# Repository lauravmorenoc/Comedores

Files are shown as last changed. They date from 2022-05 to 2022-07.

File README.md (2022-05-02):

# Comedores
Uno de los servicios que se busca mejorar por medio del proyecto "Campus Inteligente", corresponde al servicio de comedores de la Universidad Nacional de Colombia, sede Bogotá.

## Funcionamiento actual del sistema en la Universidad
Actualmente, los usuarios se dirigen a cualquiera de los comedores de la universidad, sin conocimiento previo de qué tan lleno se encuentra. Al llegar, hacen una fila física hasta el lugar en el que se sirven los almuerzos. Una vez aquí, toman una bandeja, y los empleados van presentando las opciones disponibles (por ejemplo, para escoger entre carne de res o pollo), de las cuales los usuarios eligen su opción favorita. En base a esta información, los empleados llenan los platos, que se van colocando en la bandeja. Al finalizar, se dirigen a la caja, en donde un operador les cobra una tarifa que depende si es estudiante sin beneficio alimentario, estudiante con este beneficio u otro tipo de usuario (visitante, docente, entre otros).

La siguiente imagen resume los aspectos anteriormente mencionados



## Primera solución presentada

## regulaciones respecto al uso del espectro electromagnético.

### Espectro electromagnético
Es la distribución energética del conjunto de las ondas electromagnéticas, yendo desde la longitud de onda más grande, a la longitud de onda más pequeña (o desde la frecuencia más baja, a la frecuencia más alta).



Uno de los usos principales del espectro son las telecomunicaciones, y por esta razón está regulado por el gobierno la radiación, distribución y recepción de las diferentes frecuencias. Las bandas varían dependiendo de la frecuencia/longitud de onda en varios grupos estándar:





Comparando los diferentes estándares se ven de la siguiente forma:



Respecto al espectro hay algunas regulaciones que es pertinente mencionar en relación al proyecto.

### Regulaciones
_Basado en el decreto 1078 de 2015 y la resolución 711 de 2016 de la ANE (Agencia Nacional del Espectro)_

#### Frecuencias para aplicaciones industriales, científicas y médicas (ICM)
Funcionamiento de equipos o de instalaciones destinados a producir y utilizar, en un espacio reducido, energía radioeléctrica con fines industriales, científicos y médicos, domésticos o similares, con exclusión de todas las aplicaciones de telecomunicación. Se muestran en la siguiente tabla:



Estas frecuencias pueden ser usadas para radiocomunicaciones de corto alcance (RCA), pero el usuario deben aceptar la potencial interferencia que se puede producir.

#### Frecuencias restringidas

Con el fin de evitar posibles interferencias a comunicaciones radioeléctricas sensibles tales como radionavegación aeronáutica, radioastronomía, operaciones de búsqueda y rescate y comunicaciones móviles, entre otras, los dispositivos de radiocomunicaciones de corto alcance y baja potencia (RCA) no podrán funcionar en las bandas descritas en la siguiente tabla:



#### Radiador intencional/radio aficionado
_Radiador intencional: Persona con interés en hacer algún tipo de transmisión usando el espectro._
_Radioaficionado: Persona con interés no comercial de hacer algún tipo de transmisión usando el espectro_

Para usar el espectro de forma comercial, la persona/entidad debe registrarse en el registro único del MINTIC, y ya que el uso será comercial, deben pagar contraprestaciones (impuestos) por el uso del espectro.

Los radioaficionados pueden usar el espectro sin pagar contraprestaciones. existen tres tipos de licencias para radioaficionados:

- Segunda o de Novicio
- Primera o de Experto
- Avanzada

#### Límites para radiadores intencionales o radio aficionados

A menos de estar incluido en alguna de las excepciones, las emisiones de cualquier radiador intencional no deberán superar los niveles de intensidad de campo que se especifican en la siguiente tabla:



A su vez estas son las restricciones de bandas y tipo de emisión:





#### Antenas

No se permite la operación de dispositivos con antenas diferentes a las suministradas o recomendadas por el fabricante, así mismo, no se pueden usar antenas que permitan que el sistema exceda los límites de potencia o campo eléctrico establecidos por regulación.

#### Referencias

https://www.suin-juriscol.gov.co/viewDocument.asp?id=30019521
https://normograma.mintic.gov.co/mintic/docs/pdf/resolucion_ane_0711_2016.pdf

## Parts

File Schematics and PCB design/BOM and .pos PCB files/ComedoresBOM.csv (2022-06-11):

Id | Designator | Package | Quantity | Designation | Supplier and ref
1 | C_k1,C14,C1 | C_1206_3216Metric_Pad1.33x1.80mm_HandSolder | 3 | 10u
2 | C8,C7,C6,C5 | C_1206_3216Metric_Pad1.33x1.80mm_HandSolder | 4 | 22u
3 | C4,C2 | C_0805_2012Metric_Pad1.18x1.45mm_HandSolder | 2 | 0.1u
4 | C3 | C_1206_3216Metric_Pad1.33x1.80mm_HandSolder | 1 | 47u
5 | R4 | R_0805_2012Metric_Pad1.20x1.40mm_HandSolder | 1 | 1.1k
6 | R3 | R_0805_2012Metric_Pad1.20x1.40mm_HandSolder | 1 | 1k
7 | R2,R1 | R_0805_2012Metric_Pad1.20x1.40mm_HandSolder | 2 | 1
8 | C9,C11,C12,C13,C10 | C_0805_2012Metric_Pad1.18x1.45mm_HandSolder | 5 | 100n
9 | U4 | SOT-223-3_TabPin2 | 1 | AMS1117-3.3
10 | R11,R6 | R_0805_2012Metric_Pad1.20x1.40mm_HandSolder | 2 | 10k
11 | R9,R5 | R_0805_2012Metric_Pad1.20x1.40mm_HandSolder | 2 | 51k
12 | SW5 | TerminalBlock_Altech_AK300-2_P5.00mm | 1 | FW
13 | J4 | PinSocket_1x07_P2.54mm_Vertical | 1 | Conn_audio
14 | R7 | R_0805_2012Metric_Pad1.20x1.40mm_HandSolder | 1 | 470
15 | J1 | PinHeader_1x06_P2.54mm_Vertical | 1 | Conn_display2
16 | J6 | PinSocket_1x02_P2.54mm_Vertical | 1 | Salida_amp
17 | D1 | LED_0805_2012Metric_Pad1.15x1.40mm_HandSolder | 1 | Green
18 | R12,R19,R8,R16,R15,R17,R18,R10,R13,R14 | R_0805_2012Metric_Pad1.20x1.40mm_HandSolder | 10 | 5.1k
19 | D2 | LED_0805_2012Metric_Pad1.15x1.40mm_HandSolder | 1 | Red
20 | SW4 | TerminalBlock_Altech_AK300-2_P5.00mm | 1 | BW
21 | J2 | JST_EH_B8B-EH-A_1x08_P2.50mm_Vertical | 1 | Conn_display_2
22 | J3 | JST_EH_B7B-EH-A_1x07_P2.50mm_Vertical | 1 | Conn_teclado
23 | SW3 | SW_SPST_EVQQ2 | 1 | SW_Push
24 | U2 | ESP32-WROOM-32 | 1 | ESP32-WROOM-32
25 | L1 | L_6.3x6.3_H3 | 1 | 10u
26 | U3 | PinSocket_1x06_P2.54mm_Vertical | 1 | FT232
27 | U1 | TP5410 | 1 | Tp5400
28 | J7 | JST_EH_B2B-EH-A_1x02_P2.50mm_Vertical | 1 | Entrada_buzzer
29 | J5 | USB_Mini-B_AdamTech_MUSB-B5-S-VT-TSMT-1_SMD_Vertical | 1 | USB_B_Mini
30 | D3 | SS32 | 1 | SS32
31 | BT1 | JST_PH_B2B-PH-K_1x02_P2.00mm_Vertical | 1 | Battery_Cell
32 | L2 | L_6.3x6.3_H3 | 1 | 33u
33 | SW1 | SW_SPST_CK_RS282G05A3 | 1 | SW_Push

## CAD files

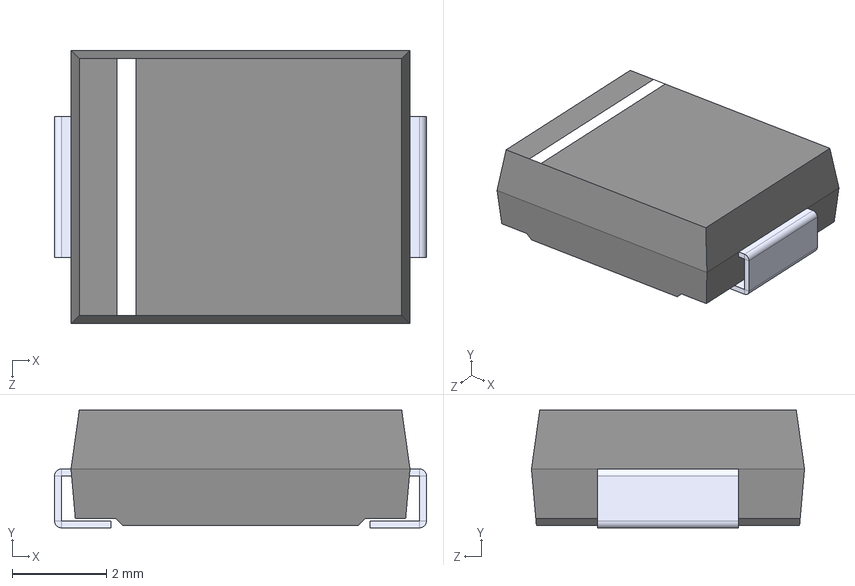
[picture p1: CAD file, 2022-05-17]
Schematics and PCB design/Final Schematic/SS32/SS32.step
7.90 x 2.50 x 5.80 mm

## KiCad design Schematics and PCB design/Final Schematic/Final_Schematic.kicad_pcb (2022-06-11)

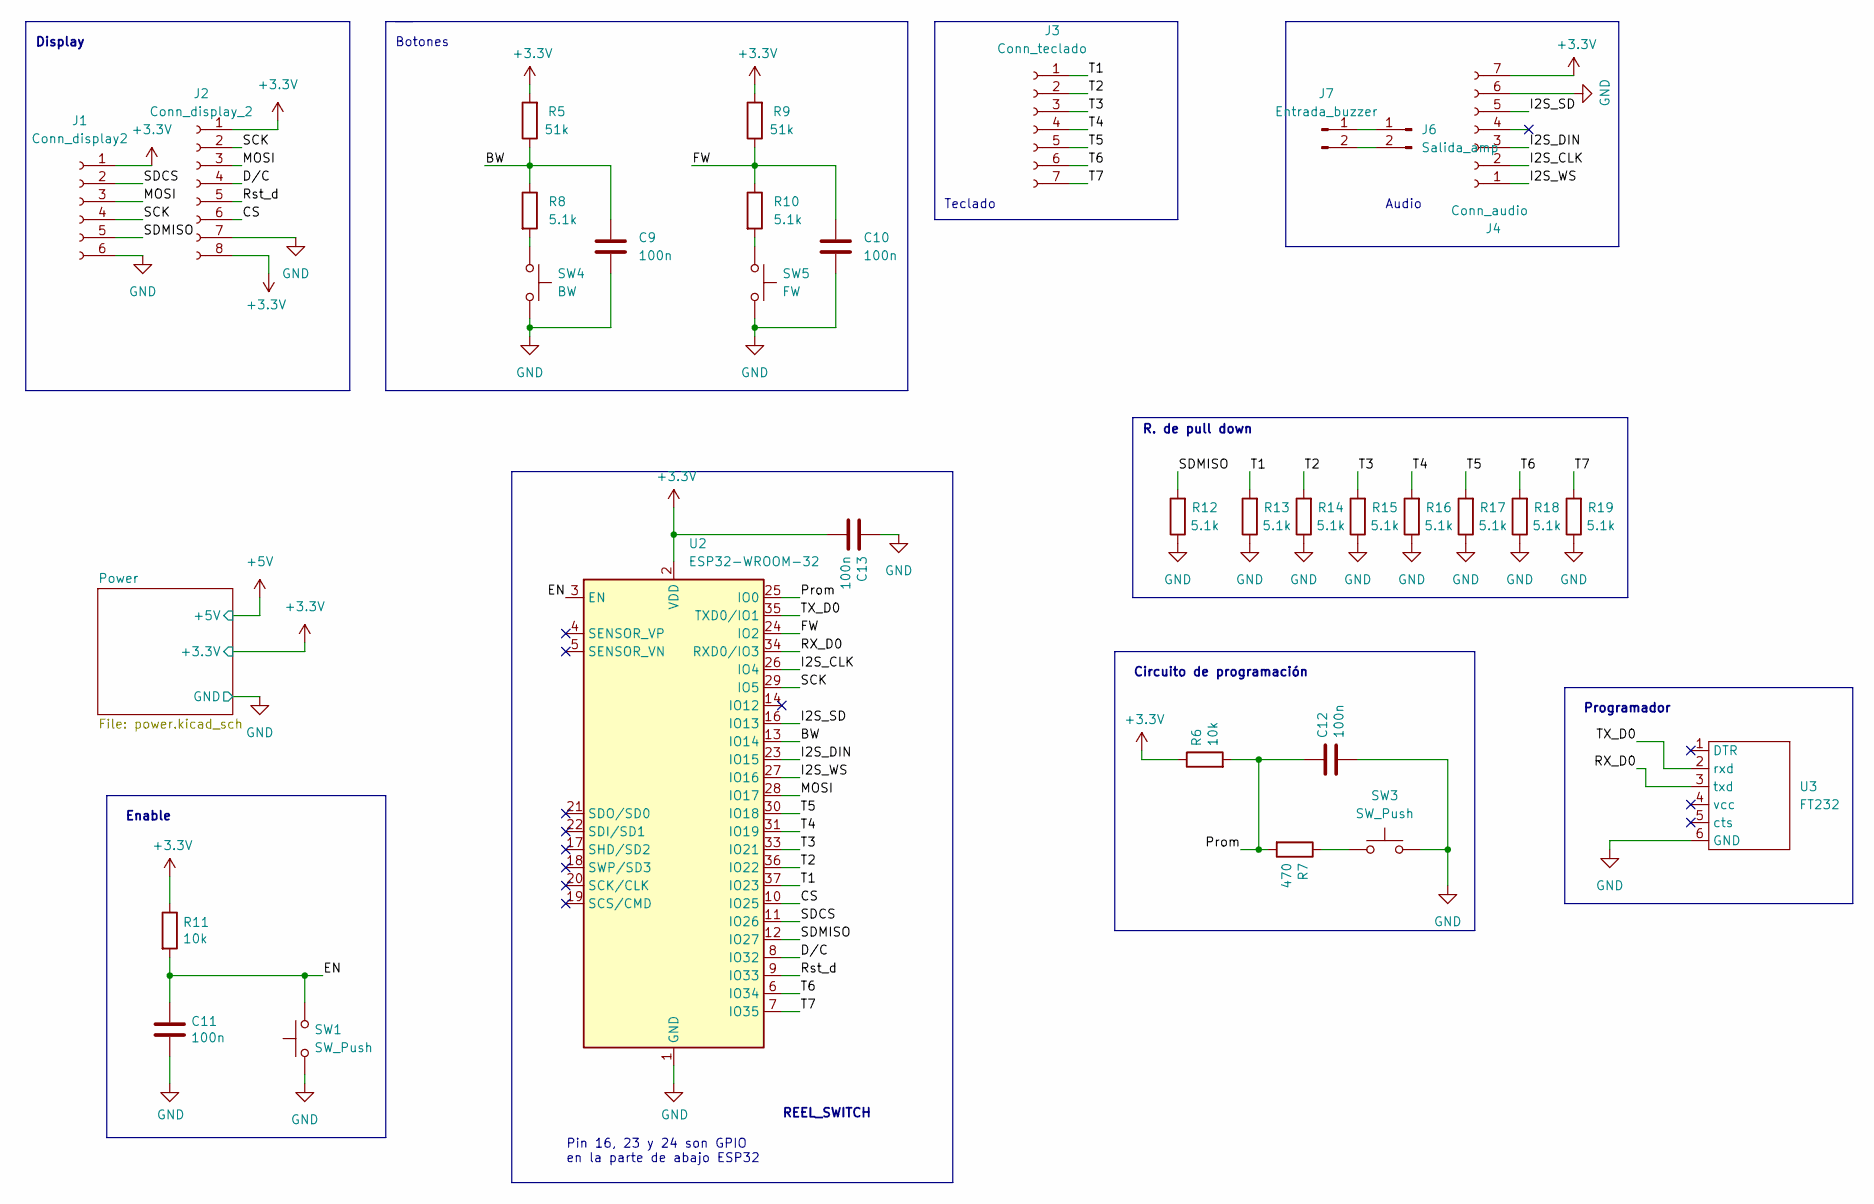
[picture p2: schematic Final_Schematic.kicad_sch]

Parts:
C9, C10, C11, C12, C13: 100n; C_0805_2012Metric_Pad1.18x1.45mm_HandSolder
J1: Conn_display2; PinHeader_1x06_P2.54mm_Vertical
J2: Conn_display_2; JST_EH_B8B-EH-A_1x08_P2.50mm_Vertical
J3: Conn_teclado; JST_EH_B7B-EH-A_1x07_P2.50mm_Vertical
J4: Conn_audio; PinSocket_1x07_P2.54mm_Vertical
J6: Salida_amp; PinSocket_1x02_P2.54mm_Vertical
J7: Entrada_buzzer; JST_EH_B2B-EH-A_1x02_P2.50mm_Vertical
R5, R9: 51k; R_0805_2012Metric_Pad1.20x1.40mm_HandSolder
R6, R11: 10k; R_0805_2012Metric_Pad1.20x1.40mm_HandSolder
R7: 470; R_0805_2012Metric_Pad1.20x1.40mm_HandSolder
R8, R10, R12, R13, R14, R15, R16, R17, R18, R19: 5.1k; R_0805_2012Metric_Pad1.20x1.40mm_HandSolder
SW1: SW_Push; SW_SPST_CK_RS282G05A3
SW3: SW_Push; SW_SPST_EVQQ2
SW4: BW; TerminalBlock_Altech_AK300-2_P5.00mm
SW5: FW; TerminalBlock_Altech_AK300-2_P5.00mm
U2: ESP32-WROOM-32
U3: FT232; PinSocket_1x06_P2.54mm_Vertical

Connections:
+3V3: C13.2, J1.1, J2.1, J2.8, J4.7, R5.2, R6.1, R9.2, R11.1, U2.2 (VDD); also elsewhere on the board
/BW: C9.2, R5.1, R8.1, U2.13 (IO14)
/CS: J2.6, U2.10 (IO25)
/D/C: J2.4, U2.8 (IO32)
/EN: C11.1, R11.2, SW1.2, U2.3 (EN)
/FW: C10.2, R9.1, R10.1, U2.24 (IO2)
/I2S_CLK: J4.2, U2.26 (IO4)
/I2S_DIN: J4.3, U2.23 (IO15)
/I2S_SD: J4.5, U2.16 (IO13)
/I2S_WS: J4.1, U2.27 (IO16)
/MOSI: J1.3, J2.3, U2.28 (IO17)
/Prom: C12.1, R6.2, R7.2, U2.25 (IO0)
/RX_D0: U2.34 (RXD0/IO3), U3.3 (txd)
/Rst_d: J2.5, U2.9 (IO33)
/SCK: J1.4, J2.2, U2.29 (IO5)
/SDCS: J1.2, U2.11 (IO26)
/SDMISO: J1.5, R12.2, U2.12 (IO27)
/T1: J3.1, R13.2, U2.37 (IO23)
/T2: J3.2, R14.2, U2.36 (IO22)
/T3: J3.3, R15.2, U2.33 (IO21)
/T4: J3.4, R16.2, U2.31 (IO19)
/T5: J3.5, R17.2, U2.30 (IO18)
/T6: J3.6, R18.2, U2.6 (IO34)
/T7: J3.7, R19.2, U2.7 (IO35)
/TX_D0: U2.35 (TXD0/IO1), U3.2 (rxd)
GND: C9.1, C10.1, C11.2, C12.2, C13.1, J1.6, J2.7, J4.6, R12.1, R13.1, R14.1, R15.1, R16.1, R17.1, R18.1, R19.1, SW1.1, SW3.2, SW4.2, SW5.2, U2.1 (GND), U2.15 (GND), U2.38 (GND), U2.39 (GND), U3.6 (GND); also elsewhere on the board
unnamed: J6.1, J7.1
unnamed: J6.2, J7.2
unnamed: R7.1, SW3.1
unnamed: R8.2, SW4.1
unnamed: R10.2, SW5.1

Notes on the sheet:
Circuito de programación
Botones
Pin 16, 23 y 24 son GPIO en la parte de abajo ESP32
R. de pull down
Display
Audio
Programador
Teclado
REEL_SWITCH
Enable

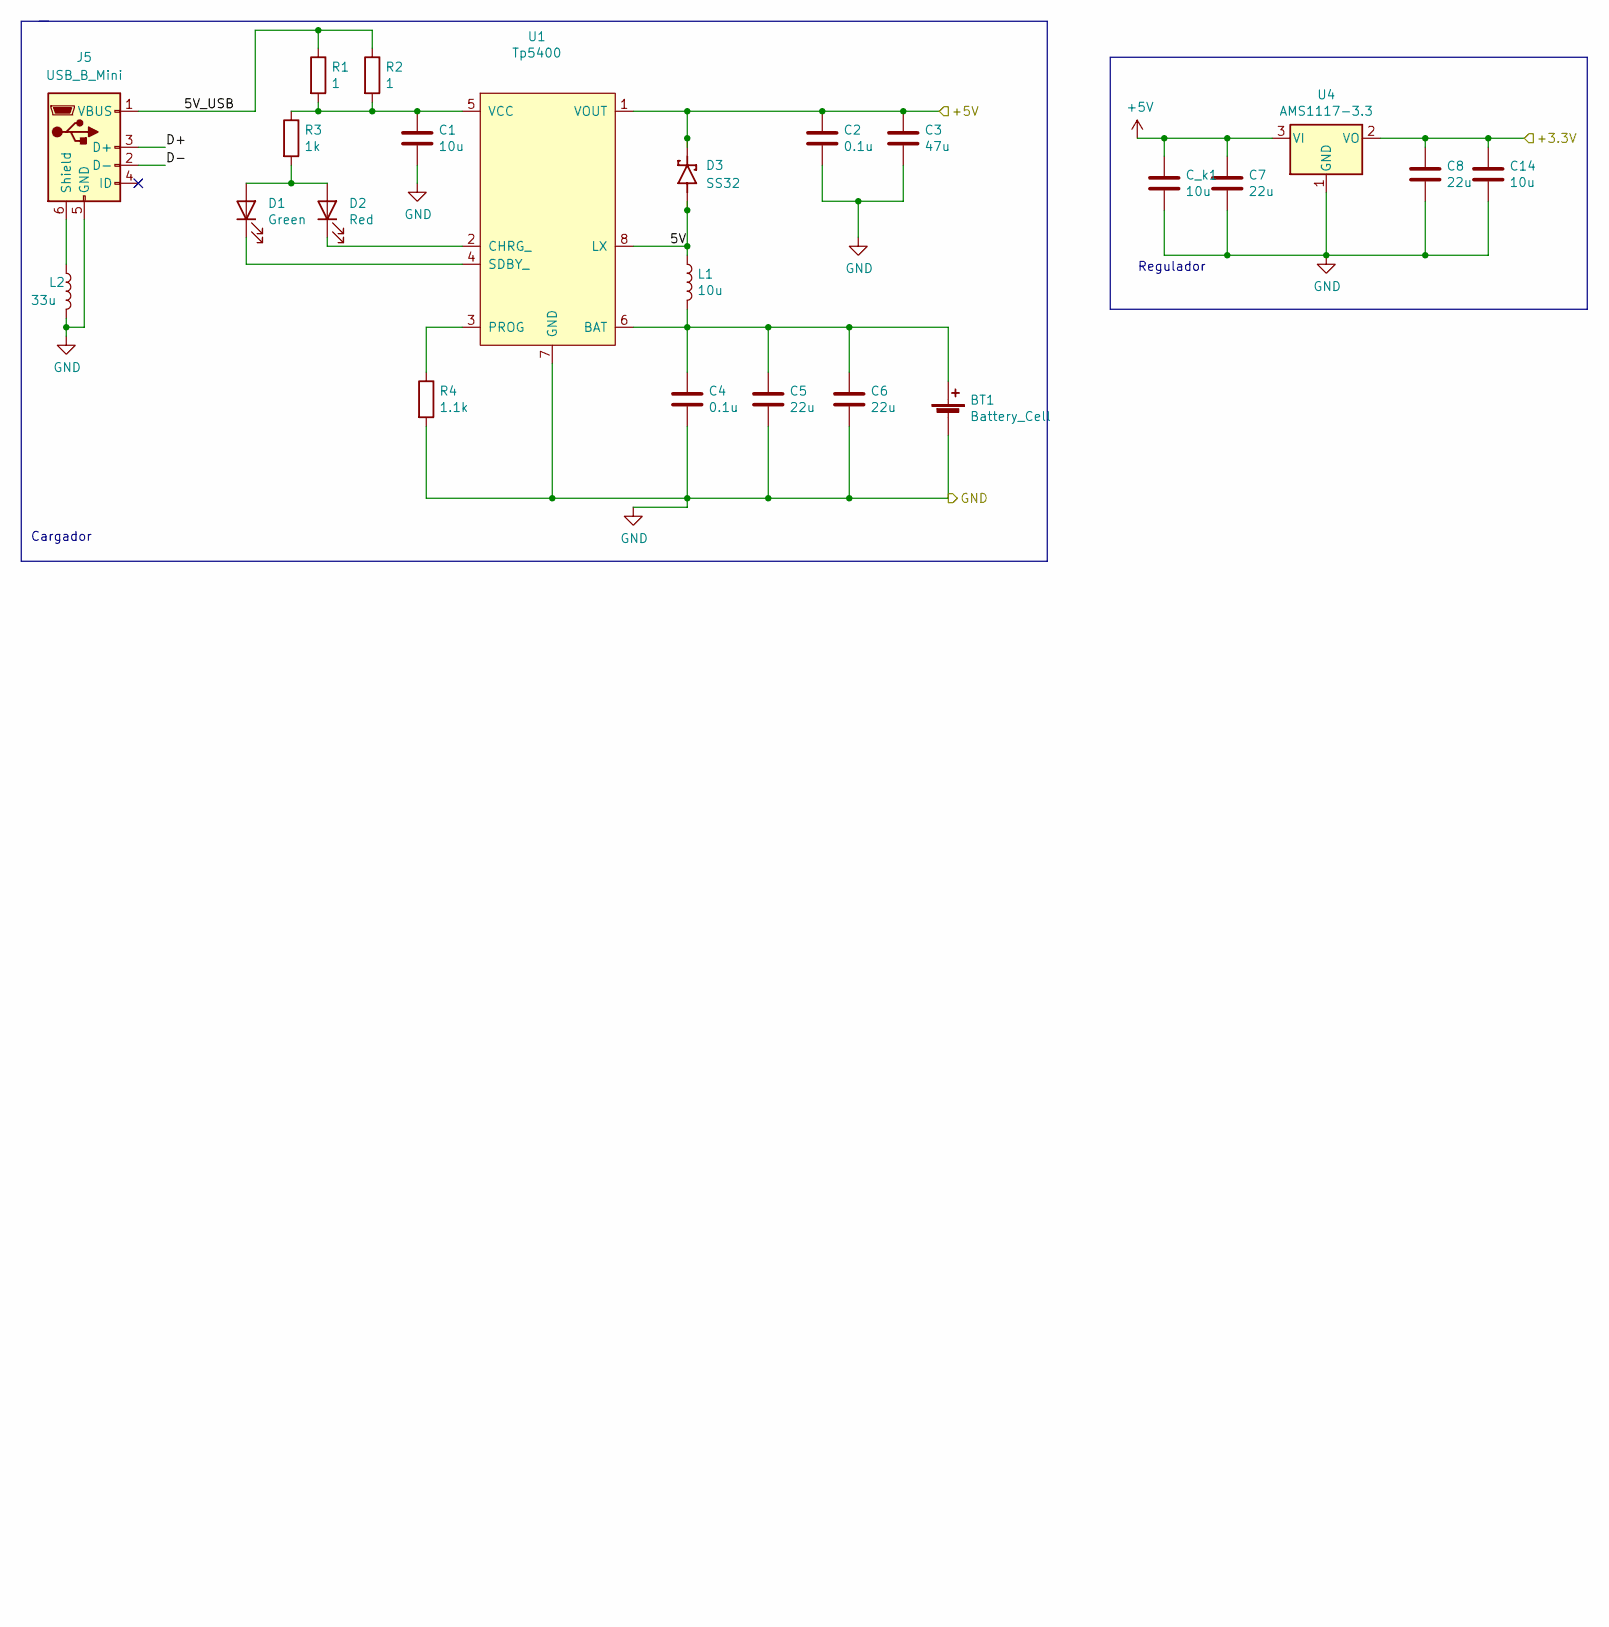
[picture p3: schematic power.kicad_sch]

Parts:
BT1: Battery_Cell; JST_PH_B2B-PH-K_1x02_P2.00mm_Vertical
C1, C14: 10u
C2, C4: 0.1u
C3: 47u
C5, C6, C7, C8: 22u
C_k1: 10u
D1: Green; LED_0805_2012Metric_Pad1.15x1.40mm_HandSolder
D2: Red; LED_0805_2012Metric_Pad1.15x1.40mm_HandSolder
D3: SS32; PARTREV Q2102
J5: USB_B_Mini; USB_Mini-B_AdamTech_MUSB-B5-S-VT-TSMT-1_SMD_Vertical
L1: 10u; L_6.3x6.3_H3
L2: 33u; L_6.3x6.3_H3
R1, R2: 1
R3: 1k
R4: 1.1k
U1: Tp5400; TP5410
U4: AMS1117-3.3; SOT-223-3_TabPin2

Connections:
+3V3: C8.1, C14.1, U4.2 (VO); also elsewhere on the board
+5V: C2.1, C3.1, C7.1, C_k1.1, D3.C, U1.1 (VOUT), U4.3 (VI)
/Power/5V: D3.A, L1.1, U1.8 (LX)
/Power/5V_USB: J5.1 (VBUS), R1.1, R2.1
/Power/D+: J5.3 (D+)
/Power/D-: J5.2 (D-)
GND: BT1.2 (-), C1.2, C2.2, C3.2, C4.2, C5.2, C6.2, C7.2, C8.2, C14.2, C_k1.2, J5.5 (GND), L2.2, R4.2, U1.7 (GND), U4.1 (GND); also elsewhere on the board
unnamed: BT1.1 (+), C4.1, C5.1, C6.1, L1.2, U1.6 (BAT)
unnamed: C1.1, R1.2, R2.2, R3.1, U1.5 (VCC)
unnamed: D1.1 (K), U1.4 (SDBY_)
unnamed: D1.2 (A), D2.2 (A), R3.2
unnamed: D2.1 (K), U1.2 (CHRG_)
unnamed: J5.6 (Shield), L2.1
unnamed: R4.1, U1.3 (PROG)

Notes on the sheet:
Regulador
Cargador

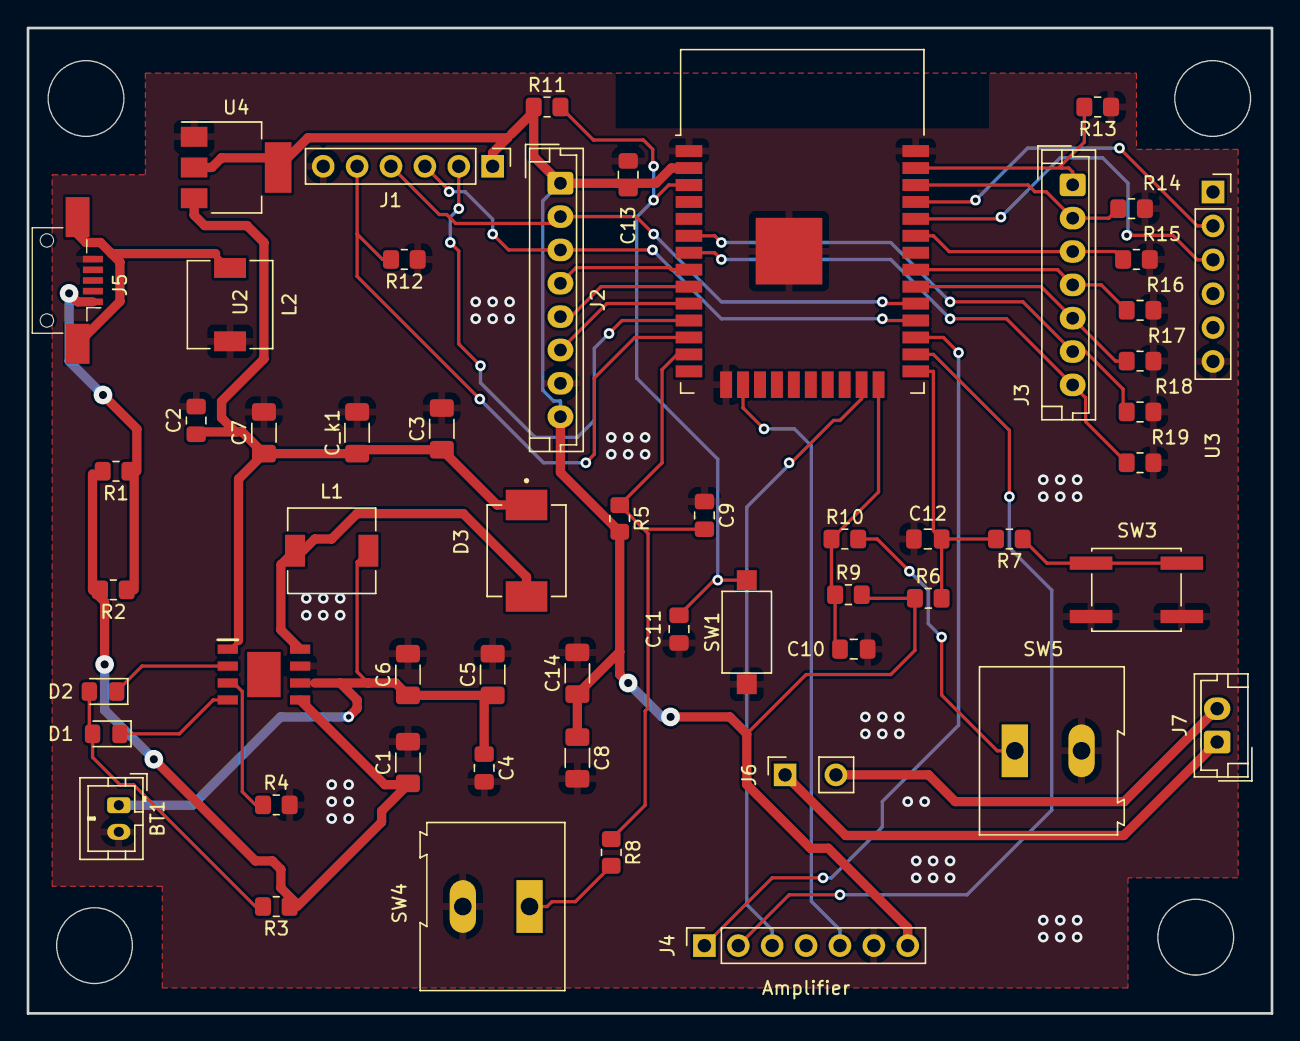
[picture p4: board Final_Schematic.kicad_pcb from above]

Board: 2 copper layers, 93.2 x 73.9 mm, 55 parts (0 on the bottom side), 41 nets.

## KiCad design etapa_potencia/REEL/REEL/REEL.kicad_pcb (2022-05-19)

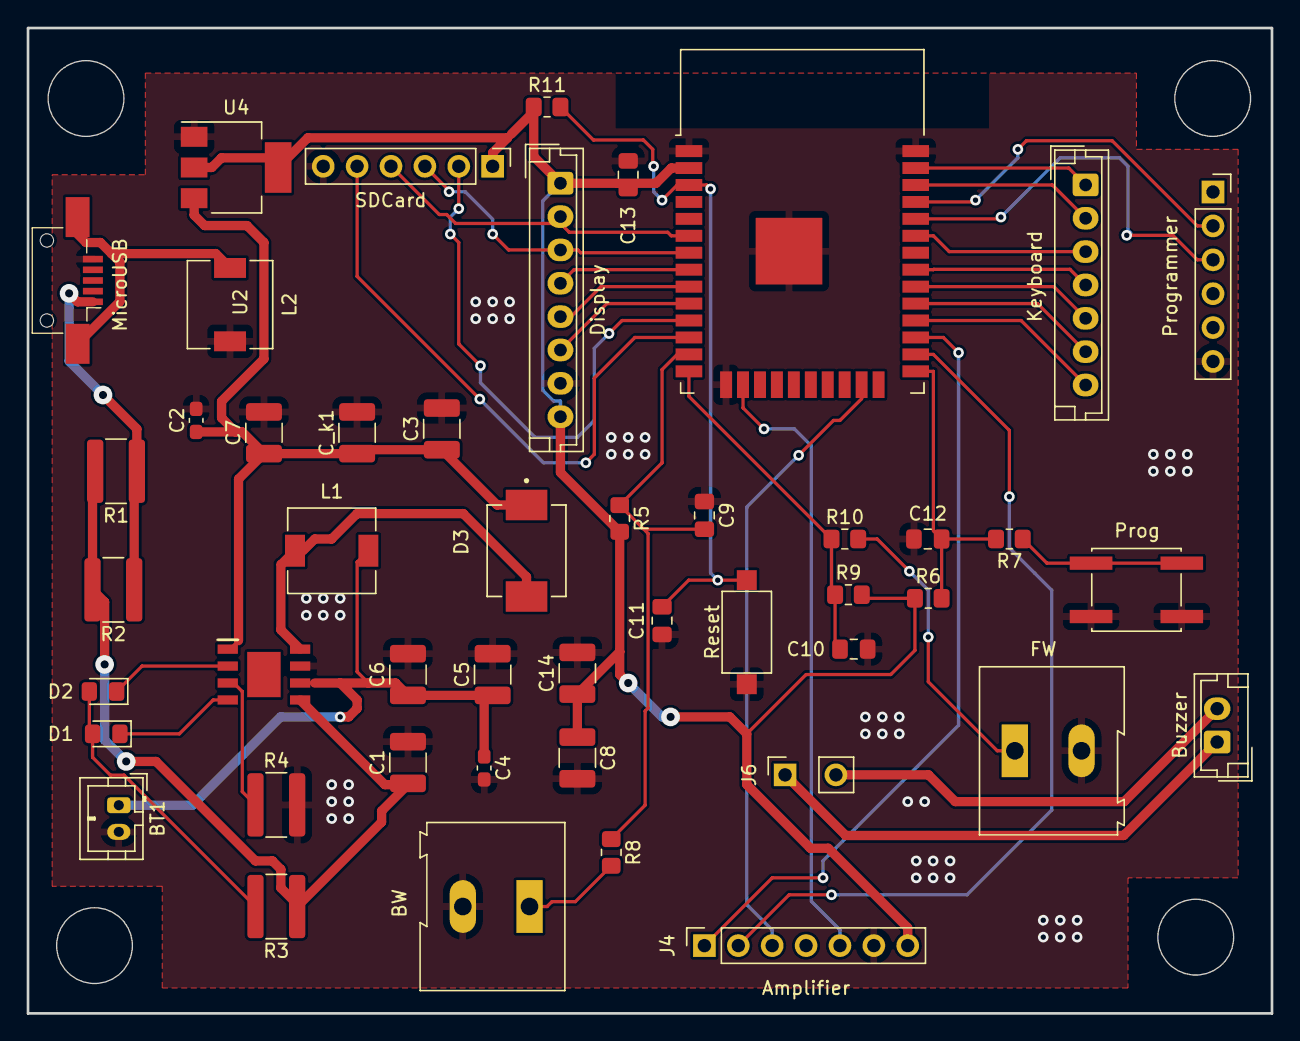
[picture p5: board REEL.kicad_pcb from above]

Board: 2 copper layers, 93.2 x 73.9 mm, 47 parts (0 on the bottom side), 41 nets.

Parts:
BT1: Battery_Cell; JST_PH_B2B-PH-K_1x02_P2.00mm_Vertical
BW: BW; TerminalBlock_Altech_AK300-2_P5.00mm
Buzzer: Entrada_buzzer; JST_EH_B2B-EH-A_1x02_P2.50mm_Vertical
C1, C14: 10u; C_1210_3225Metric_Pad1.33x2.70mm_HandSolder
C2, C4: 0.1u; C_0603_1608Metric_Pad1.08x0.95mm_HandSolder
C3: 47u; C_1210_3225Metric_Pad1.33x2.70mm_HandSolder
C5, C6, C7, C8: 22u; C_1210_3225Metric_Pad1.33x2.70mm_HandSolder
C9, C10, C11, C12, C13: 100n; C_0805_2012Metric_Pad1.18x1.45mm_HandSolder
C_k1: 10u; C_1210_3225Metric_Pad1.33x2.70mm_HandSolder
D1: Green; LED_0805_2012Metric_Pad1.15x1.40mm_HandSolder
D2: Red; LED_0805_2012Metric_Pad1.15x1.40mm_HandSolder
D3: SS32
Display: Conn_display_2; JST_EH_B8B-EH-A_1x08_P2.50mm_Vertical
FW: FW; TerminalBlock_Altech_AK300-2_P5.00mm
J4: Conn_audio; PinSocket_1x07_P2.54mm_Vertical
J6: Salida_amp; PinSocket_1x02_P2.54mm_Vertical
Keyboard: Conn_teclado; JST_EH_B7B-EH-A_1x07_P2.50mm_Vertical
L1: 10u; L_6.3x6.3_H3
L2: 33u; L_6.3x6.3_H3
MicroUSB: USB_B_Mini; USB_Mini-B_AdamTech_MUSB-B5-S-VT-TSMT-1_SMD_Vertical
Prog: SW_Push; SW_SPST_EVQQ2
Programmer: FT232; PinSocket_1x06_P2.54mm_Vertical
R1, R2: 1; R_1218_3246Metric_Pad1.22x4.75mm_HandSolder
R3: 1k; R_1218_3246Metric_Pad1.22x4.75mm_HandSolder
R4: 1.1k; R_1218_3246Metric_Pad1.22x4.75mm_HandSolder
R5, R9: 51k; R_0805_2012Metric_Pad1.20x1.40mm_HandSolder
R6, R11: 10k; R_0805_2012Metric_Pad1.20x1.40mm_HandSolder
R7: 470; R_0805_2012Metric_Pad1.20x1.40mm_HandSolder
R8, R10: 5.1k; R_0805_2012Metric_Pad1.20x1.40mm_HandSolder
Reset: SW_Push; SW_SPST_CK_RS282G05A3
SDCard: Conn_display2; PinHeader_1x06_P2.54mm_Vertical
U1: Tp5400; TP5410
U2: ESP32-WROOM-32
U4: AMS1117-3.3; SOT-223-3_TabPin2

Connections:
+3V3: C8.1, C13.2, C14.1, Display.1, Display.8, J4.7, R5.2, R6.1, R9.2, R11.1, SDCard.1, U2.2 (VDD), U4.2 (VO)
+5V: C2.1, C3.1, C7.1, C_k1.1, D3.C, U1.1 (VOUT), U4.3 (VI)
/BW: C9.2, R5.1, R8.1, U2.13 (IO14)
/CS: Display.6, U2.10 (IO25)
/D/C: Display.4, U2.8 (IO32)
/EN: C11.1, R11.2, Reset.2, U2.3 (EN)
/FW: C10.2, R9.1, R10.1, U2.14 (IO12)
/I2S_CLK: J4.2, U2.26 (IO4)
/I2S_DIN: J4.3, U2.23 (IO15)
/I2S_SD: J4.5, U2.16 (IO13)
/I2S_WS: J4.1, U2.27 (IO16)
/MOSI: Display.3, SDCard.3, U2.7 (IO35)
/Power/5V: D3.A, L1.1, U1.8 (LX)
/Power/5V_USB: MicroUSB.1 (VBUS), R1.1, R2.1
/Prom: C12.1, R6.2, R7.2, U2.25 (IO0)
/RX_D0: Programmer.3 (txd), U2.34 (RXD0/IO3)
/Rst_d: Display.5, U2.9 (IO33)
/SCK: Display.2, SDCard.4, U2.6 (IO34)
/SDCS: SDCard.2, U2.11 (IO26)
/SDMISO: SDCard.5, U2.12 (IO27)
/T1: Keyboard.1, U2.37 (IO23)
/T2: Keyboard.2, U2.36 (IO22)
/T3: Keyboard.3, U2.33 (IO21)
/T4: Keyboard.4, U2.31 (IO19)
/T5: Keyboard.5, U2.30 (IO18)
/T6: Keyboard.6, U2.29 (IO5)
/T7: Keyboard.7, U2.28 (IO17)
/TX_D0: Programmer.2 (rxd), U2.35 (TXD0/IO1)
GND: BT1.2 (-), BW.2, C1.2, C2.2, C3.2, C4.2, C5.2, C6.2, C7.2, C8.2, C9.1, C10.1, C11.2, C12.2, C13.1, C14.2, C_k1.2, Display.7, FW.2, J4.6, L2.2, MicroUSB.5 (GND), Prog.2, Programmer.6 (GND), R4.2, Reset.1, SDCard.6, U1.7 (GND), U2.1 (GND), U2.15 (GND), U2.38 (GND), U2.39 (GND), U4.1 (GND)
unnamed: BT1.1 (+), C4.1, C5.1, C6.1, L1.2, U1.6 (BAT)
unnamed: C1.1, R1.2, R2.2, R3.1, U1.5 (VCC)
unnamed: D1.1 (K), U1.4 (SDBY_)
unnamed: D1.2 (A), D2.2 (A), R3.2
unnamed: D2.1 (K), U1.2 (CHRG_)
unnamed: L2.1, MicroUSB.6 (Shield)
unnamed: Buzzer.1, J6.1
unnamed: Buzzer.2, J6.2
unnamed: R4.1, U1.3 (PROG)
unnamed: Prog.1, R7.1
unnamed: BW.1, R8.2
unnamed: FW.1, R10.2

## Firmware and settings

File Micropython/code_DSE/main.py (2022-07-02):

# Main Code
from MQTTconnection import *
from mainMQTT import Communications
from displayLib import MyDisplay
from ili9341 import Display, color565
from machine import Pin, SPI
from xglcd_font import XglcdFont
from machine import SoftSPI
import math
from wavplayer import WavPlayer
import os

sck=5
mosi=19
miso=23

spi=SoftSPI(baudrate=1000000, polarity=0, phase=0, sck=Pin(sck, Pin.OUT), mosi=Pin(mosi, Pin.OUT), miso=Pin(miso, Pin.OUT))
disp=MyDisplay(spi)
disp.printLogo()
disp.printText('Ticket: ', vspace=1, hspace=8)

COMM=Communications()

sim_ticket=0

last_publish_time = 0
message_interval = 2 # in seconds
refresh = True
comedor=1
cash_register_on=False
ID=''
IDcounter=0


##

SCK_PIN = 26 #32
WS_PIN = 22 #25
SD_PIN = 21 #33
I2S_ID = 0
BUFFER_LENGTH_IN_BYTES = 5000

global local_ticket
local_ticket=0
last_ticket=0

wp = WavPlayer(id=I2S_ID,
              sck_pin=Pin(SCK_PIN),
              ws_pin=Pin(WS_PIN),
              sd_pin=Pin(SD_PIN),
              ibuf=BUFFER_LENGTH_IN_BYTES)
#---- AUDIO CONFIG

push_button = Pin(25, Pin.IN)  # 23 number pin is input
bw_button = Pin(27, Pin.IN)





## TECLADO ##
TECLA_ARRIBA  = const(0)
TECLA_ABAJO = const(1)

teclas = [['1', '2', '3', 'A'], ['4', '5', '6', 'B'], ['7', '8', '9', 'C'], ['*', '0', '#', 'D']]

# Pines del GPIO  
filas = [23,22,21,19] 
columnas = [18,34,35,12] 

# define los pines de filas como salidas
fila_pines = [Pin(nombre_pin, mode=Pin.OUT) for nombre_pin in filas]

# define los pines de columnas como entradas
columna_pines = [Pin(nombre_pin, mode=Pin.IN, pull=Pin.PULL_DOWN) for nombre_pin in columnas]

def tec_init():
    for fila in range(0,4):
        for columna in range(0,4):
            fila_pines[fila].low()
    print("Teclado en espera")


def scan(fila, columna):
    """ escanea todo el teclado """

    # define la columna actual en alto -high-
    fila_pines[fila].high()
    tecla = None

    # verifica por teclas si hay teclas presionadas
    if columna_pines[columna].value() == TECLA_ABAJO:
        tecla = TECLA_ABAJO
    if columna_pines[columna].value() == TECLA_ARRIBA:
        tecla = TECLA_ARRIBA
    fila_pines[fila].low()

    # devuelve el estado de la tecla
    return tecla

# define todas las columnas bajo -low-
tec_init()








def char_type(char):
    if char=='1' or char=='2' or char=='3' or char=='4' or char=='5' or char=='6' or char=='7' or char=='8' or char=='9' or char=='0':
        return 'Number'
    elif char=='*': #Asterisco
        return 'Ast'
    elif char=='#': #Numeral
        return 'Sharp'
    
def button_verify():
    
    global local_ticket

    logic_state = push_button.value()
    bw_logic_state= bw_button.value()
  
    if logic_state == True or bw_logic_state== True:     # if pressed the push_button
    
        if bw_logic_state == True:
            local_ticket=local_ticket-1
            print("if: Turno ")
            print(local_ticket)
        else:
            local_ticket = local_ticket+1
            print("else: Turno")
            print(local_ticket)

while True:    
    
    COMM.check_message()
    
    #### Función para simular avance de turnos, se puede quitar
    try:
        if (time.time() - last_publish_time) > message_interval:
            if refresh:
                #COMM.send(topic='SI/Petition')
                #COMM.send(topic='Easymeals/Update', ticket=sim_ticket, comedor=comedor)
                #COMM.send(topic='TEMPERATURE')
                refresh = False
                #sim_ticket+=1
                #local_ticket+=1
            else:
                refresh = True
            last_publish_time = time.time()
    except OSError as e:
        print('Unable to connect. Please restart device.')
    ####
    
    
# Send messages
    button_verify()
    
    if local_ticket!=last_ticket:
        try:
            COMM.send(topic='Easymeals/Update', ticket=local_ticket, comedor=comedor)
        except OSError as e:
            print('OSError: Unable to sent ticket update. Please restart device.')
        last_ticket=local_ticket


# Receive messages
    topic, message, pending_incoming_message=COMM.receive()
    if pending_incoming_message==True:
        if str(topic,'utf-8')=='Easymeals/Payment':
            if message["Registered"]:
                Name=message["Name"]
                Rol=message["Rol"]
                disp.printText('Name:', vspace=5, hspace=1)
                disp.printText(Name, vspace=6, hspace=1)
                disp.printText('Rol:', vspace=8, hspace=1)
                disp.printText(Rol, vspace=9, hspace=1)
                if Rol=='Student':
                    Payment=5900 
                else:
                    Payment=7900 # Cambiar si incorrecto
                disp.printText('Total amount to pay: ', vspace=11, hspace=1)
                disp.printText('$'+str(Payment), vspace=12, hspace=8)
                cash_register_on=True
            else:
                disp.printText('User not registered', vspace=5, hspace=3)
                cash_register_on=False
        elif str(topic,'utf-8')=='Easymeals/Update':
            if message["Comedor"]==comedor:
                ticket=message["ticket"]
                disp.printText('    ', vspace=3, hspace=11)
                disp.printText(str(ticket), vspace=3, hspace=11)
                cash_register_on=False
                
                wp.play("turno.wav", loop= False)
                while wp.isplaying() == True:
                    pass
                
                # Delete last users'data from display
                disp.printText('      ', vspace=5, hspace=1)
                disp.printText('                     ', vspace=6, hspace=1)
                disp.printText('            ', vspace=9, hspace=1)
                disp.printText('Digite su numero de identificacion:', vspace=8, hspace=1)
                disp.printText('                     ', vspace=11, hspace=1)
                disp.printText('      ', vspace=12, hspace=8)
                
                num_file = str(ticket) + ".wav"
                
                if ticket <= 9:
                    wp.play(num_file, loop= False)
                    while wp.isplaying() == True: 
                        pass
                elif ticket >= 10 and ticket <= 99:
                    tens = ticket // 10
                    unit = ticket % 10
                    wp.play(str(tens) + ".wav", loop= False)
                    while wp.isplaying() == True:
                        pass
                    wp.play(str(unit) + ".wav", loop= False)
                    while wp.isplaying() == True: 
                        pass
            
        COMM.pending_incoming_message=False    
            
        
    # Sent messages
    
    # La función de Juan debe tener un print. Cambiar ese print por, considerando 'out' lo que se imprime:

    
    for fila in range(4):
        for columna in range(4):
            tecla = scan(fila, columna)
            if tecla == TECLA_ABAJO:
                print("Tecla Presionada", teclas[fila][columna])
                out=teclas[fila][columna]
    
    if !cash_register_on: # Awaiting to get key from keyboard
        if char_type(out) =='Number':
            disp.printText(out,vspace=9, hspace=IDcounter)
            ID=ID+out
            IDcounter+=1

        elif char_type(out) =='Ast':
            disp.printText(' ' ,vspace=9, hspace=IDcounter-1)
            ID=ID[0:len(ID)-1] # verificar
            IDcounter-=1

        elif char_type(out) =='Sharp':
            try:
                COMM.send(topic='Easymeals/Payment', userID=ID)
                print('Sending ID to SI')
                cash_register_on=True
            except OSError as e:
                print('OSError: Unable to send ID')
    

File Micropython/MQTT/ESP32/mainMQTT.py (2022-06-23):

from MQTTconnection import *

class Communications:
        
    
    def __init__(self):

        # WLAN network
        net_name = "LA.CONSENTIDA"
        net_password = "13g8o5l3d21"
        #net_name = "Omega-9523"
        #net_password = "12345678"
        #net_name = "UNAL"
        #net_password = ""

        conect_to(net_name,net_password)

        try:
            self.client = connect_and_subscribe()
            self.localID='2'
            self.ticket=0 # Current ticket
            self.last_topic='SI/Petition'
            self.last_message={"LocalID":"1"}
            self.pending_incoming_message=False
            self.last_pending=False
        except OSError as e:
            restart_and_reconnect()

    def check_message(self):
        self.client.check_msg()
    
    def receive(self):
        topic, message = getValues()
        if self.pending_incoming_message==False and  self.pending_incoming_message!=self.last_pending:
            self.last_topic=str(topic,'utf-8')
            self.last_message=message
        if (str(topic,'utf-8')!= self.last_topic) or (message!=self.last_message):
            self.pending_incoming_message=True
        self.last_pending=self.pending_incoming_message
        return topic, message, self.pending_incoming_message

    def send(self, topic, userID='', ticket=0, comedor=1):
        data={'LocalID':self.localID,
            'group': 3
            }
        if topic=='Easymeals/Payment':
            data={
            'LocalID':self.localID,
            'ID': userID
            }
            self.client.publish(topic, json.dumps(data),True,1)
        elif topic=='Easymeals/Update':
            data={
            'LocalID':self.localID,
            'ticket': ticket,
            'Comedor':comedor
            }
            if ticket!=0:
                self.ticket=ticket
            self.client.publish(topic, json.dumps(data),True,1)
        elif topic=='SI/Petition':
            print('Loop SI availability secured', '\n')
            self.client.publish('SI/Petition', json.dumps(data),True,1)
        elif topic=='TEMPERATURE':
            self.client.publish('TEMPERATURE', 'Holi',True,1)
        else:
            print('Misstyped topic')
        

    def sendTest(self):

        last_publish_time = 0
        message_interval = 2
        received = True
    
        myMsg={
            'LocalID':'2',
            'ID': '101006'
            }
    
        while True:
          try:
            #client.check_msg()
            if (time.time() - last_publish_time) > message_interval:
                if received:
                    self.client.publish('SI/Petition', json.dumps(myMsg),True,1)
                    received = False
                else:
                 #   client.check_msg()
                    received = True
                last_publish_time = time.time()
          except OSError as e:
            restart_and_reconnect()

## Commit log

2022-04-22 Esquemático en Kicad con interfaz y botón de reset
    [Omega2.kicad_pcb, Omega2.kicad_sch]
2022-04-25 Actualización de funcionamiento actual
2022-04-25 Update README.md
    Adición de normas ambientales
2022-04-28 Organización display, botón de reset, power flag
    [Omega2.kicad_pcb, Omega2.kicad_sch]
2022-05-02 Adicion botones
    [Omega2.kicad_sch]
2022-05-02 Adición Teclado
    [Omega2.kicad_sch]
2022-05-06 edición pulsadores
    [Omega2.kicad_sch]
2022-05-07 edicion pcb
    [Omega2.dsn, Omega2.kicad_pcb, Omega2.kicad_sch]
2022-05-07 Prueba de ruteo
    [Omega2.dsn, Omega2.kicad_pcb]
2022-05-10 Adición módulo amplificación separado
    [Adafruit MAX98357 Breakout.kicad_pcb, Adafruit MAX98357 Breakout.kicad_sch]
2022-05-12 Adición etapa de audio
    [REEL.kicad_pcb, REEL.kicad_sch]
2022-05-12 cambios etapa audio
    [REEL.kicad_sch]
2022-05-12 Edicion display y botones
    [REEL.kicad_sch]
2022-05-13 Conexiones corregidas, PCB ordenada
    [REEL.kicad_pcb, REEL.kicad_sch, power.kicad_sch]
2022-05-13 adicion matriz vias
    [REEL.kicad_pcb]
2022-05-15 Primera organización huellas
    Organización de huellas y conectores, falta parte de potencia
    [REEL.kicad_pcb, REEL.kicad_sch, power.kicad_sch]
2022-05-16 Cambios en diagrama, separacion tierras, y capacitores
    [REEL.kicad_pcb, REEL.kicad_sch, power.kicad_sch]
2022-05-17 modificaciones por caras
    [REEL.kicad_pcb, REEL.kicad_sch, SS32.step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]
2022-05-17 Ubicación definida de los elementos
    [REEL.kicad_pcb]
2022-05-17 Reorganización pcb
    Después de primera revisión del profe Camargo
    [REEL.kicad_pcb, REEL.kicad_sch, power.kicad_sch]
2022-05-17 Ordenar huellas en PCB ahora sí
    [REEL.kicad_pcb, REEL.kicad_sch, power.kicad_sch]
2022-05-17 PCB lista para rutear
    [REEL.kicad_pcb]
2022-05-17 Cambio orden pines etapa de audio
    [REEL.kicad_pcb, REEL.kicad_sch]
2022-05-17 Primer ruteo PCB
    [REEL.kicad_pcb]
2022-05-19 Adición conector de tarjeta SD
    [REEL.kicad_pcb, REEL.kicad_sch]
2022-05-19 Nombres en capa silkscreen
    [REEL.kicad_pcb]
2022-05-19 Edicion pcb rutas
    [REEL.kicad_pcb]
2022-05-20 Últimos arreglos PCB
    Resistencias de pull down de teclado y pin MISO de la sd, pin 12 queda libre, pines 34 y 35 quedan de entrada únicamente.
    [REEL.kicad_pcb, REEL.kicad_sch]
2022-05-20 Corrección errores DCR
    [REEL.kicad_pcb]
2022-05-21 Archivos gerber, drill, BOM y pos
    [ComedoresBOM.csv, ComedoresBOM.xls, ComedoresBOM.xlsx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]
2022-05-25 Organización y adición de códigos Micropython
    Organización de carpetas, adición de código MQTT 1.0 y primera prueba con Display
    [ComedoresBOM.csv, ComedoresBOM.xls, ComedoresBOM.xlsx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]
2022-05-25 Organización carpetas again
    [ComedoresBOM.csv, ComedoresBOM.xls, Final_Schematic.kicad_pcb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]
2022-05-31 Commit de prueba
2022-05-31 Commit de prueba x2
2022-06-14 Función completa de display y logo UN
2022-06-17 MQTT module updated
    PC reads ID correctly and returns data dictionary. However, the ESP is publishing back what it is receiving from PC. Working on it.
    [MQTTconnection.py, mainMQTT.py]
2022-06-20 Update display ticket from communications module tested
    Falta integrar funciones de teclado, botones y audio
2022-06-21 Minor changes
    Cambié el last_pending...=false para que fuera general en el main, agregué que mire si el comedor al actualizar el turno coincide, y que mire si la persona está registrada para imprimir el nombre o p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
2022-06-21 pre-keyboard function and SI broker added
    [MQTTconnection.py, main.py, mainMQTT.py]
2022-06-21 Buttons and audio union to main code
